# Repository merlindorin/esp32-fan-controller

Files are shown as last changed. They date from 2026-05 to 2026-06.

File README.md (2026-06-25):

<div align="center">

# ESP32 Fan Controller

**A small KiCad board to keep my home server cabinet cool. 4 PWM fans, 4 temperature probes, one ESP32.**








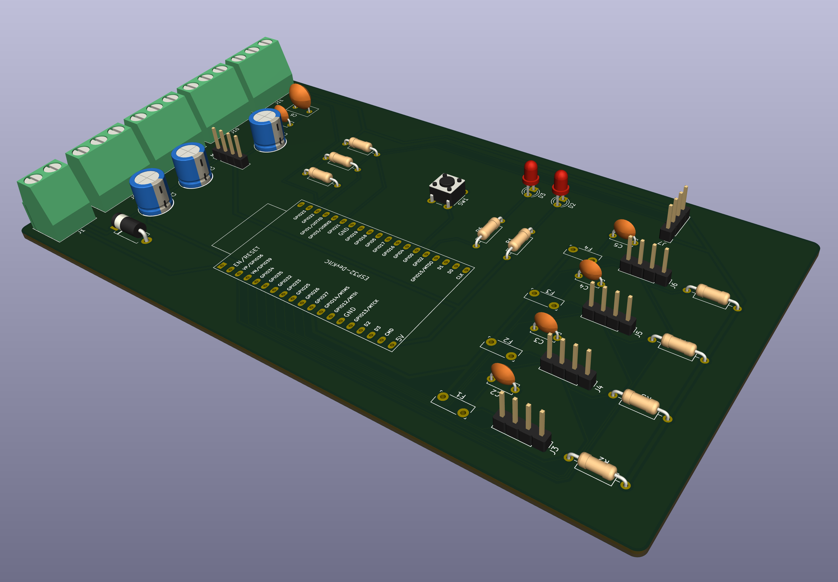
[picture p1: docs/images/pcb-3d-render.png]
ESP32 Fan Controller, KiCad 3D render


</div>

## Why this exists

My home servers live in a small cabinet, hidden inside a piece of furniture I built around them. It is a credenza with a stone top, a perforated metal grille set into that top so the warm air can escape upward, and cane mesh side panels so fresh air can come in from below.

The room itself has air conditioning, but the cabinet does not. Without something actively pushing the warm air out, it just stacks up under the stone. So I needed a way to manage the airflow.

<table align="center">
  <tr>
    <td align="center">
      <a href="docs/images/server-cabinet.jpg">The server cabinet, with the perforated stone-top grille and cane-mesh panels, click for full size</a>
    </td>
  </tr>
  <tr>
    <td align="center"><sub>The cabinet. Stone top with the perforated exhaust grille against the wall, servers behind the cane mesh panels.</sub></td>
  </tr>
</table>

I started with two breadboard prototypes (see [How I got here](#how-i-got-here)). The first one was just about understanding the temperatures: where to put the probes, where it actually gets hot. The second one was for the fans, to see how they really move the air through that perforated stone grille.

Once both questions were answered, I designed this PCB. It is a small two layer board, all through-hole so I can solder it by hand on a Sunday afternoon, around €14 in parts. It runs [ESPHome](https://esphome.io/), which means it shows up directly in Home Assistant without writing any firmware.

The board is now soldered, mounted at the back of the cabinet, and the firmware in [`firmware/fancontroller.yaml`](firmware/fancontroller.yaml) keeps the two pairs of fans (one per side of the cabinet) under thermostatic control. A short press on the on-board button toggles between auto and manual; the yellow LED reflects that state.

<table align="center">
  <tr>
    <td align="center" width="50%">
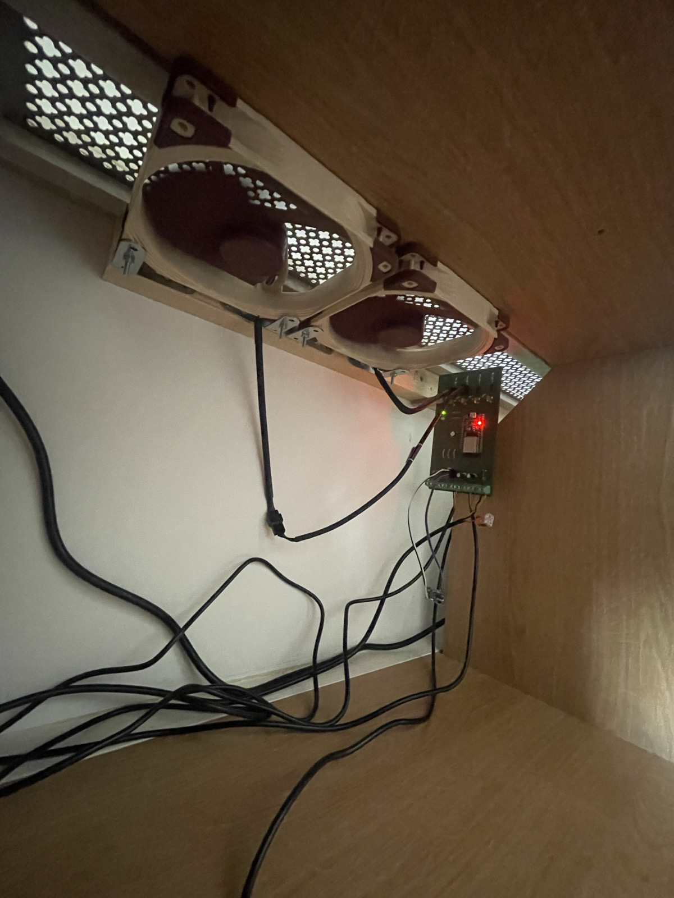
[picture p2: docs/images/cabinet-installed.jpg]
Two Noctua fans pulling air up through the perforated stone grille, controller mounted on the right wall of the cabinet, click for full size
      
    </td>
    <td align="center" width="50%">
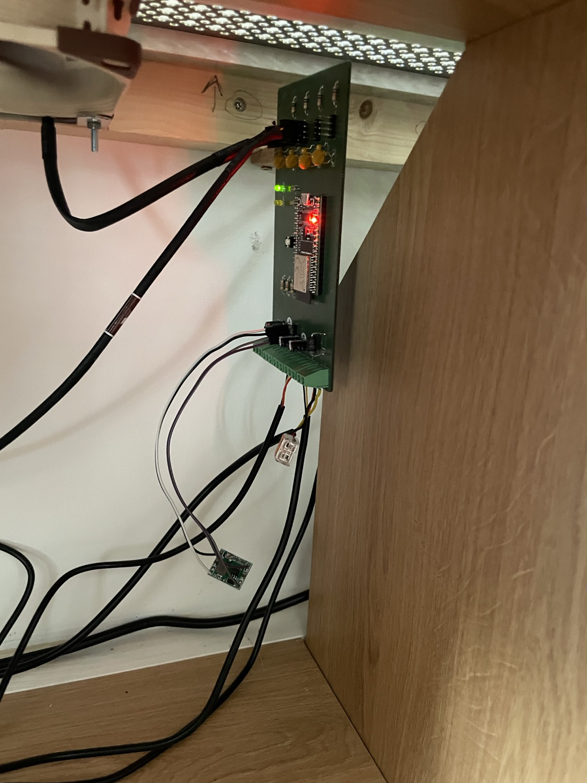
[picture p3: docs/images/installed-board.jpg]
The assembled controller mounted vertically inside the cabinet, with the DS18B20 probe and a fan cable plugged in, click for full size
      
    </td>
  </tr>
  <tr>
    <td align="center"><sub>Fans pulling air up through the perforated stone grille, controller mounted on the right wall.</sub></td>
    <td align="center"><sub>Board mounted vertically inside the cabinet, screw terminals on top, ESP32 power LED on.</sub></td>
  </tr>
</table>

## Contents

- [Features](#features)
- [Hardware overview](#hardware-overview)
  - [ESP32 GPIO map](#esp32-gpio-map)
- [Firmware (ESPHome)](#firmware-esphome)
- [How I got here](#how-i-got-here)
- [Build one yourself](#build-one-yourself)
- [Repository layout](#repository-layout)
- [Roadmap](#roadmap)
- [Discussion](#discussion)
- [License](#license)
- [Thanks](#thanks)

## Features

- 4 independent PWM fan channels (designed around Noctua NF-A14 PWM, but any standard 4-pin PC fan works)
- 4 tachometer (RPM) inputs, open-collector, with on-board pull-ups to 3.3 V
- 4 DS18B20 1-Wire temperature probes on a shared bus (single 4.7 kΩ pull-up)
- Single 12 V external input. An on-board MP1584EN buck module generates the 5 V for the ESP32
- Per-fan PTC fuse and a TVS diode at the 12 V input, for protection
- I²C expansion header (3.3 V / GND / SDA / SCL)
- Two indicator LEDs: a green one for power (lit when the 5 V rail is up) and a yellow one for status (driven by GPIO 2)
- A small tactile button for boot / user input, shared with GPIO 0
- Everything through-hole, so it can be hand-soldered without a reflow oven
- Bare board, 155 × 85 mm, with M3 mounting holes

## Hardware overview

| Block | Component |
|---|---|
| MCU | ESP32 DevKitC V4 (AZDelivery, 100 % Espressif layout) |
| Power | External 12 V / 2 A PSU, then on-board MP1584EN buck to 5 V |
| Fans | 4 Noctua NF-A14 PWM, plugged into 4-pin headers |
| Sensors | 4 DS18B20 waterproof probes on screw terminals |
| Protection | 1.5KE15A TVS on the 12 V input, 4 MF-R050 PTC fuses on the fans |
| Enclosure  | No enclosure for v1, just M3 mounting holes on the bare board |

PCB is two-layer, 155 × 85 mm, 1.6 mm thick.

<table align="center">
  <tr>
    <td align="center" width="50%">
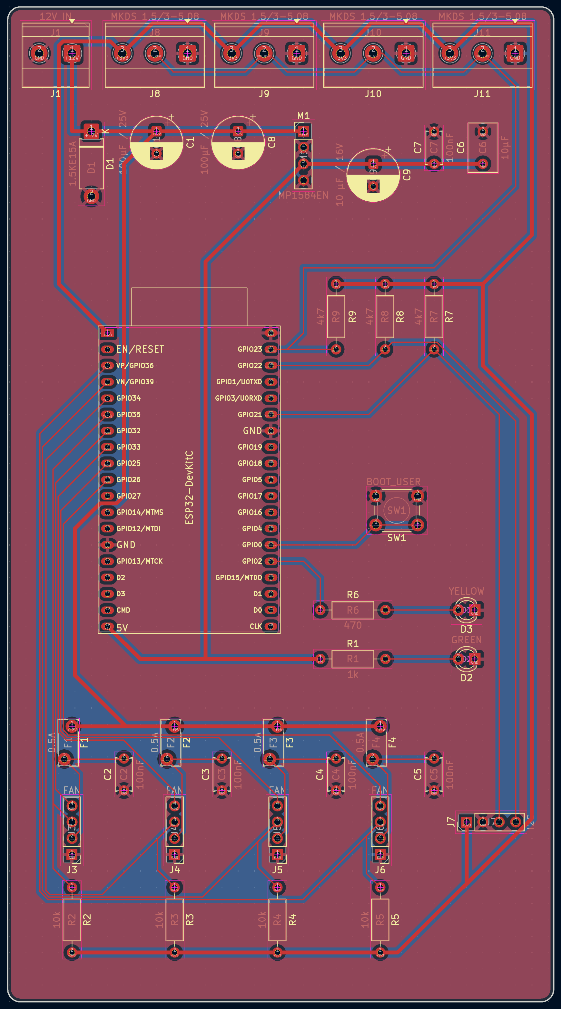
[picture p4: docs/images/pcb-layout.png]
PCB top-down layout, click for full size
      
    </td>
    <td align="center" width="50%">
      <a href="docs/images/pcb-3d-render.png">KiCad 3D render, click for full size</a>
    </td>
  </tr>
  <tr>
    <td align="center"><sub>2D layout. F.Cu in red, B.Cu in blue.</sub></td>
    <td align="center"><sub>KiCad 3D render of the assembled board.</sub></td>
  </tr>
</table>

### ESP32 GPIO map

| Connector | Side  | PWM (out) | Tach (in) |
|---|---|---|---|
| J3 | Right | GPIO 32 | GPIO 35 |
| J4 | Right | GPIO 33 | GPIO 34 |
| J5 | Left  | GPIO 25 | GPIO 39 |
| J6 | Left  | GPIO 26 | GPIO 36 |

| Pin | Use |
|---|---|
| 23 | 1-Wire bus (DS18B20 probes) |
| 21 / 22 | I²C SDA / SCL |
| 2 | Status LED (D3 yellow, R6 470 Ω) |
| 0 | Boot / user button (SW1) |

The probe on J8 covers the left fans (J5 + J6), the probe on J9 covers the right ones (J3 + J4). All four DS18B20 sockets (J8–J11) sit on the same 1-Wire bus, so the assignment is by ROM address in the YAML.

## Firmware (ESPHome)

The shipped firmware is [`firmware/fancontroller.yaml`](firmware/fancontroller.yaml). It exposes, in Home Assistant:

- Two fan controls (`Left Fans`, `Right Fans`), each driving that side's two fans in lockstep, plus an individual RPM sensor per physical fan (four in total, so a single seized fan is still visible)
- Two temperature probes (`Left Temp`, `Right Temp`) with their DS18B20 ROM addresses pinned
- A single `Auto Cooling` switch and three `Number` entities (`Cooling Setpoint`, `Fans Off Below`, `Fans Full Above`)
- A `Restart` button and a `User Button` binary sensor for the on-board SW1

When `Auto Cooling` is on, each side runs the same linear ramp on its own probe:

```
T ≤ Off Below            →   0 %     (silent)
Off Below < T < Setpoint →   0 → 60 % (gentle correction)
Setpoint ≤ T < Full Above → 60 → 100 % (aggressive)
T ≥ Full Above           → 100 %     (max effort)
```

The setpoint sits inside the band on purpose, so a stable cabinet parks the fans at around 60 % instead of oscillating between full speed and off. All three thresholds are editable live from HA; defaults are 24 / 27 / 30 °C.

The on-board button toggles `Auto Cooling` on a short press, and reboots the ESP32 on a 3 s+ hold. The yellow LED follows `Auto Cooling`: on in auto, off in manual.

### Autonomous by design

The control loop runs entirely on the board, not in Home Assistant. That is deliberate. Each server already manages its own temperature through its own fans; this controller's job is to keep the enclosure itself in range, and it has to keep doing that even when nothing is around to tell it to.

Home Assistant here runs on one of my Kubernetes nodes, which lives in the very rack this board is cooling. Relying on it to cool the rack it runs in is a chicken-and-egg problem: if that node is the one overheating, HA could be the first thing to go down. So the thermostatic logic lives on the ESP32 itself. If HA is unreachable, the board keeps reading its probes and driving the fans on its own, the servers keep handling their own thermal management, and everything stays under control independently.

The result is layered, autonomous cooling instead of a central brain that could take itself down and put the other nodes at thermal risk. Home Assistant is for visibility and live tuning, not a dependency for the rack to stay cool.

<table align="center">
  <tr>
    <td align="center" width="50%">
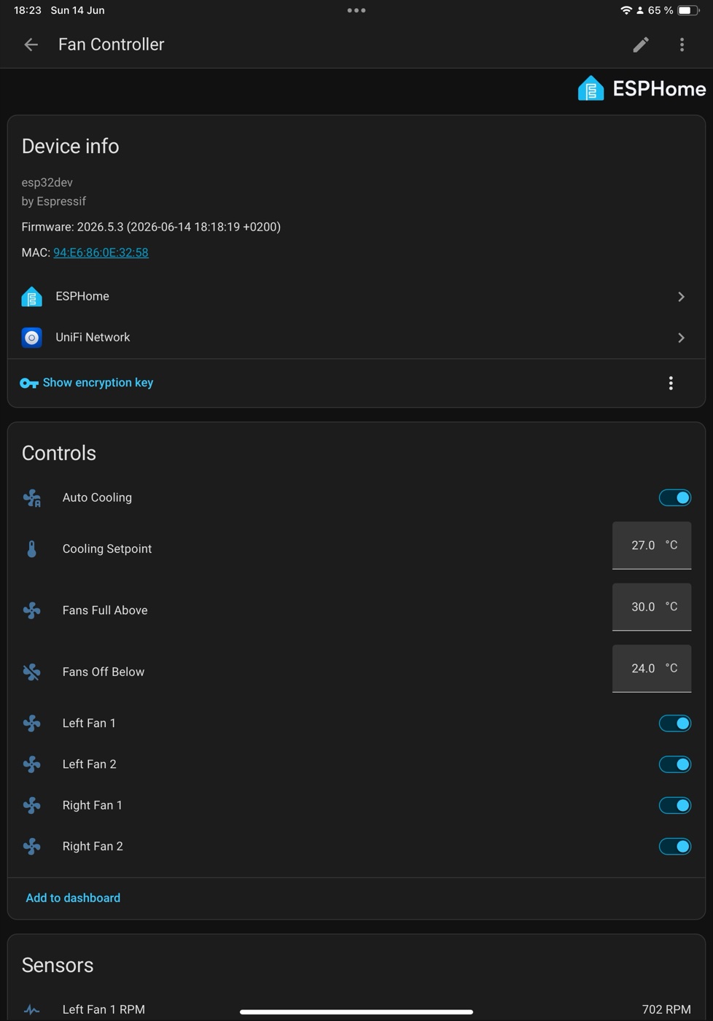
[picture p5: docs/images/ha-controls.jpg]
Home Assistant device controls: Auto Cooling switch, three setpoint numbers, two fan toggles, click for full size
      
    </td>
    <td align="center" width="50%">
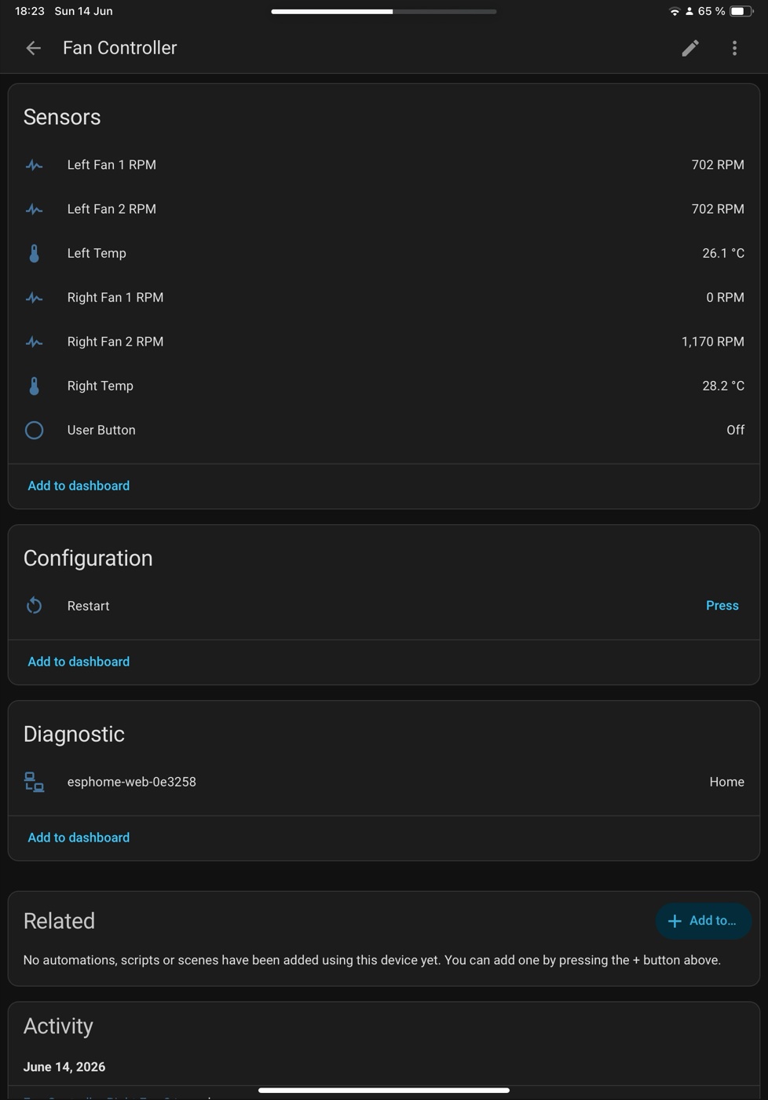
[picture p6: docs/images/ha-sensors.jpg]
Home Assistant sensors page: left and right RPM and temperatures, click for full size
      
    </td>
  </tr>
  <tr>
    <td align="center"><sub>Device controls: auto cooling, thresholds, per-side fan toggles.</sub></td>
    <td align="center"><sub>Sensors: per-side RPM and temperature.</sub></td>
  </tr>
</table>

The build / flash / dashboard commands are wrapped in a [`Taskfile.yml`](Taskfile.yml). With [Task](https://taskfile.dev/) installed (`brew install go-task`):

```
task               # list available tasks
task config        # validate the YAML
task upload        # compile and OTA-flash fancontroller.local
task flash-usb PORT=/dev/cu.wchusbserial8330   # first-time USB flash
task logs          # stream logs over the network
task dashboard     # local ESPHome dashboard on :6052
```

Before the first flash, copy `firmware/secrets.example.yaml` to `firmware/secrets.yaml` and fill it in (Wi-Fi, API key, OTA password). `secrets.yaml` is git-ignored.

## How I got here

Before committing to a PCB, I validated the design with two breadboard stages.

### Stage 1, temperature monitoring with Home Assistant

I started with an ESP32 **LoLin** board and **two DS18B20 probes**, flashed with [ESPHome](https://esphome.io/) and added to Home Assistant. The question for this stage was simple: what does the temperature actually do in the server cabinet? It gave me the baseline graphs that justified active cooling, and it told me where the probes should sit (intake, exhaust, ambient).

The ESPHome YAML I used is kept here for reference: [`docs/stage1-lolin32-esphome.yaml`](docs/stage1-lolin32-esphome.yaml). Shared 1-Wire bus on GPIO 4, two `dallas_temp` entries by 64-bit address.

<table align="center">
  <tr>
    <td align="center" width="50%">
      <a href="docs/images/proto-lolint-esp.jpg">ESP32 LoLin with 2 DS18B20 probes on a protoboard, click for full size</a>
    </td>
    <td align="center" width="50%">
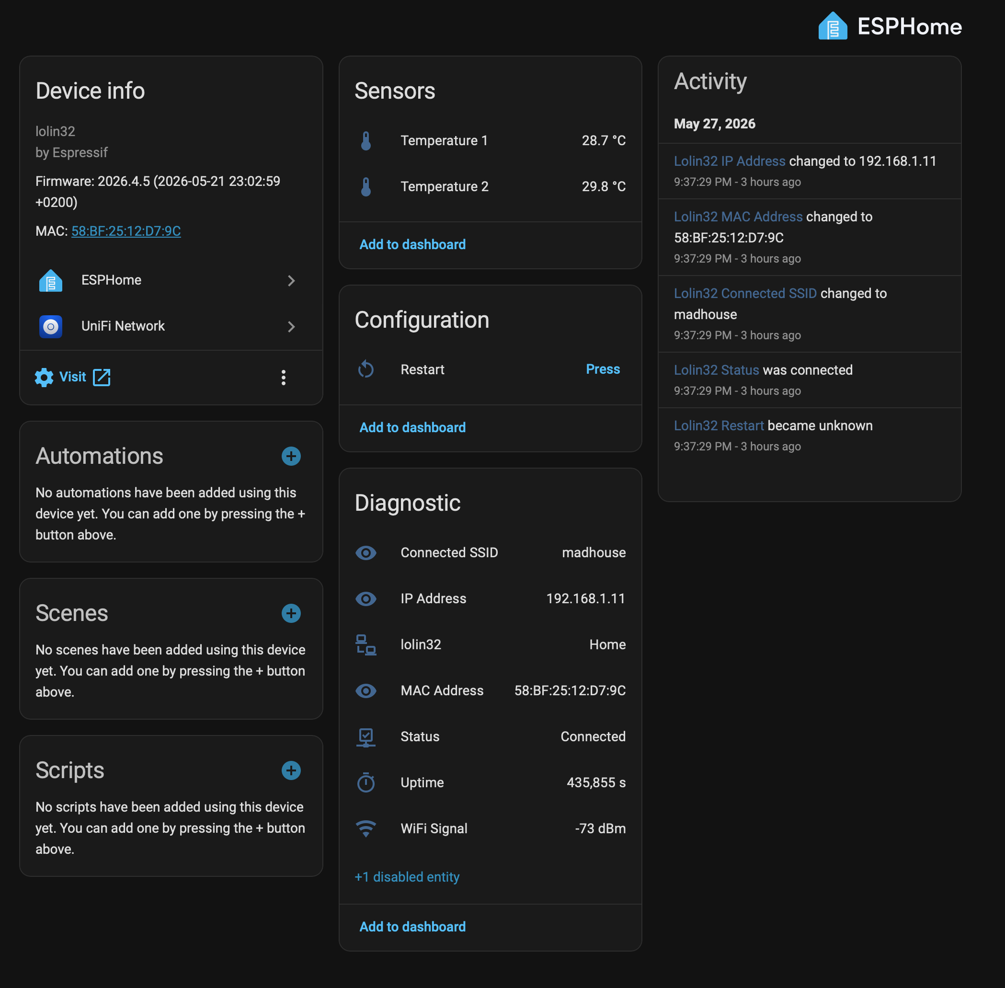
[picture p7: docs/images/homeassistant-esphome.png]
Home Assistant device page for the LoLin32, click for full size
      
    </td>
  </tr>
  <tr>
    <td align="center"><sub>ESP32 LoLin with two DS18B20 probes.</sub></td>
    <td align="center"><sub>Home Assistant device page, both probes live (28.7 °C and 29.8 °C).</sub></td>
  </tr>
</table>

### Stage 2, the fan bench

For the second stage, I drove a fan directly from a separate breadboard, to actually measure how the airflow influences the temperature. Fan position, speed versus Δtemperature, how fast the cabinet responds. This is where I confirmed that the Noctua NF-A14 was the right fan, validated the PWM strategy, and figured out the per-fan power budget.

<table align="center">
  <tr>
    <td align="center">
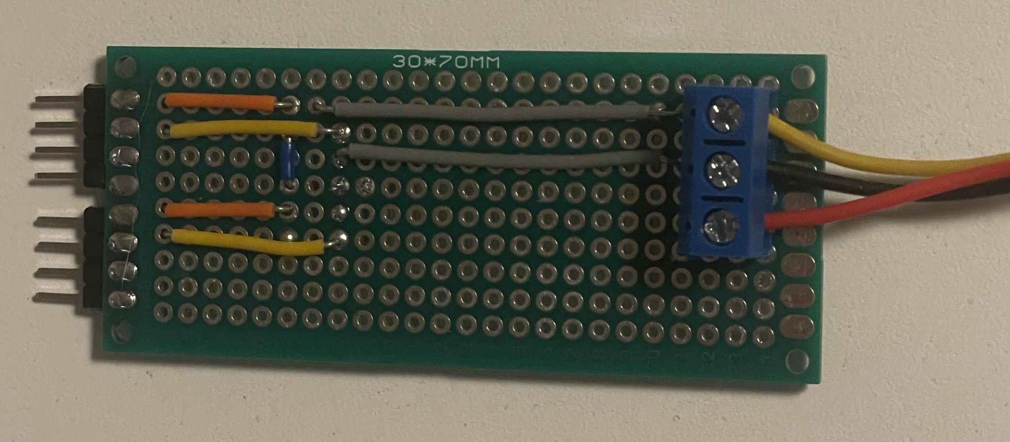
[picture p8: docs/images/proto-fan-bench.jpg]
Fan power and airflow test on a 30 by 70 mm protoboard, click for full size
      
    </td>
  </tr>
  <tr>
    <td align="center"><sub>Fan power and airflow test on a 30 × 70 mm protoboard.</sub></td>
  </tr>
</table>

The PCB in this repository is the consolidation of both stages: 4 probes (intake, exhaust, two ambient) and 4 PWM-controlled fans on a single board instead of breadboards.

## Build one yourself

1. **Order the bare PCB.** Any fab works, I used [Aisler](https://aisler.net/). You can upload `kicad/esp32-fan-controller.kicad_pro` directly, or export gerbers first if your fab needs them.
2. **Order the parts**, around €14 excluding VAT and shipping. The quick-paste block in [`bom/ORDER.md`](bom/ORDER.md) is verified against live Farnell France stock. Paste it into Farnell's Quick Paste / Multi-Add tool. The full BOM with notes is in [`BOM.md`](BOM.md).
3. **Pre-set the MP1584EN buck module to 5.00 V before soldering it in.** Apply 12 V on its input with a bench supply, and turn the trimpot until the output reads 5.00 V.
4. **Hand-solder.** All through-hole. The order I would suggest: passives, then diodes and LEDs, then sockets and headers, then screw terminals, and finally the ESP32 socket.
5. **Power-up check.** 12 V on J1, confirm 5 V at the M1 output pin, then plug in the ESP32. Watch the polarity at J1: D1 is a 1.5KE15A TVS, so a reversed wire short-circuits the input through the diode.

<table align="center">
  <tr>
    <td align="center">
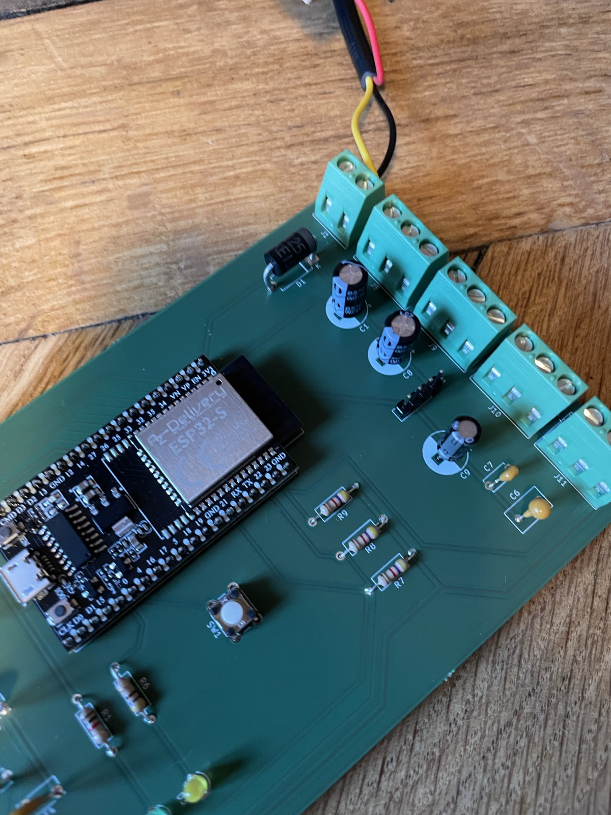
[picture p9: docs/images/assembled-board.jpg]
Assembled controller on a workbench, mid power-up check with two test leads on J1, click for full size
      
    </td>
  </tr>
  <tr>
    <td align="center"><sub>Mid power-up check: 12 V test leads on J1 before plugging in the ESP32.</sub></td>
  </tr>
</table>

6. **Flash [ESPHome](https://esphome.io/).** First time over USB, after that over the air:

   ```
   cp firmware/secrets.example.yaml firmware/secrets.yaml   # fill in Wi-Fi etc.
   task flash-usb PORT=/dev/cu.wchusbserial...              # initial flash
   task upload                                              # subsequent OTAs
   ```

   Details in [Firmware (ESPHome)](#firmware-esphome).

## Repository layout

```
.
├── kicad/                            # KiCad 10 project (schematic and PCB)
├── firmware/                         # ESPHome YAML for the v1 board
│   ├── fancontroller.yaml            # Shipped firmware
│   └── secrets.example.yaml          # Template for secrets.yaml (git-ignored)
├── bom/                              # BOM CSV and ordering sheets
│   └── orders/                       # Generated distributor cart CSVs
├── docs/
│   ├── images/                       # Photos, schematic renders, screenshots
│   └── stage1-lolin32-esphome.yaml   # ESPHome config used on the temperature prototype
├── BOM.md                            # Human-readable BOM with notes
├── Taskfile.yml                      # `task config / upload / logs / dashboard`
├── LICENSE                           # MIT
└── README.md
```

## Roadmap

**Next**

- [ ] Replace the missing right-side fan (J4) once the second NF-A14 arrives
- [ ] Long-term temperature graph in Grafana, to see how the auto-cooling curve actually plays out over a week

**Later**

- [ ] An actual enclosure for the PCB. The CamdenBoss CNMB/9 DIN-rail kit is a candidate, the board is already short-edge-connector friendly
- [ ] A v2 silkscreen polish, based on what I learned during assembly (polarity marks on J1, clearer pin-1 on the fan headers)

**Done**

- ✅ Schematic, ERC clean
- ✅ PCB layout, DRC clean, 0 violations, 0 unconnected
- ✅ Bare PCB ordered (Aisler)
- ✅ BOM verified against live Farnell stock
- ✅ Components ordered (Farnell)
- ✅ Board assembled and brought up on the bench
- ✅ Mounted in the cabinet, three fans and two DS18B20s live
- ✅ ESPHome config shipped: two per-side fan groups (4 PWM channels, 4 RPM sensors), 2 temp probes, thermostatic auto-cooling, button + LED status

## Discussion

Shared and discussed here:

- [r/esp32](https://www.reddit.com/r/esp32/comments/1ueic1q/esp32_fan_controller_for_my_home_server_cabinet/)
- [r/homeassistant](https://www.reddit.com/r/homeassistant/comments/1ueijpl/esphome_fan_controller_for_my_server_cabinet/)

## License

MIT, see [LICENSE](LICENSE). Hardware design files are released under the same terms, so feel free to fork, modify, fabricate and share.

## Thanks

- The KiCad team for the EDA suite
- Espressif for the ESP32 and the DevKitC reference design
- AZDelivery for an affordable ESP32 DevKitC V4 clone
- [ESPHome](https://esphome.io/), which turned the Stage 1 prototype into a one evening job
- [openotters](https://github.com/openotters/openotters), which I used as a template for this README

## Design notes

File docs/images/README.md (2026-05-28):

# Images

Drop project photos and screenshots here. Referenced from the top-level `README.md`.

Suggested filenames (match the references in the main README):

- `proto-lolint-esp.jpg` — Stage 1: ESP32 LoLin + 2× DS18B20 on a protoboard (present)
- `proto-fan-bench.jpg` — Stage 2: fan power / airflow test on a 30×70 mm protoboard (present)
- `proto-fan-bench.jpg` — second breadboard wired to drive fans and log temperature vs airflow
- `homeassistant-esphome.png` — Home Assistant device page for the LoLin32 (present)
- `server-cabinet.jpg` — the stone-topped server cabinet the airflow exists to manage (present)
- `kicad-schematic.png` — export of the final hierarchical schematic
- `pcb-layout.png` — KiCad PCB editor 2D top-down view (present)
- `pcb-3d-render.png` — KiCad 3D viewer render of the assembled board (present)
- `assembled-board.jpg` — final assembled board
- `enclosure-mounted.jpg` — board installed in the CamdenBoss CNMB/9 on DIN rail

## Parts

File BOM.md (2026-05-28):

# Bill of Materials — ESP32 Fan Controller

Server airflow controller: 4× PWM fans driven by ESP32, regulated from 4× DS18B20 temperature probes.

## Main components

| Qty | Part | Notes |
|----:|---|---|
| 1 | ESP32 DevKitC V4 | MCU board, mounted on PCB via female headers |
| 1 | 12V/2A PSU | External — DIN-rail (e.g. Mean Well HDR-30-12) or desktop brick |
| 1 | MP1584EN buck module (pre-built, adjustable) | 12V→5V step-down for ESP32. Pre-set trimpot to **5.00 V** before installing |
| 4 | Noctua NF-A14 PWM | 12V, 0.13A each (0.52A total on 12V rail) |
| 4 | DS18B20 waterproof probe | 1-Wire digital temp sensor, shared bus |
| 4 | Phoenix MKDS 1,5/3-5,08 (3-pin screw terminal block, 5.08 mm pitch) | For DS18B20 probes — wires enter through CNMB/9 perforated terminal guards. Pin 1=GND, Pin 2=DATA, Pin 3=+3V3. Same family as J1. |
| 4 | 4-pin PC fan header (2.54mm pitch) | **NOT** Molex KK 254 — keying differs, Noctua plugs won't mate |
| 1 | 2-pin terminal block (5.08mm pitch) | 12V input |
| 1 | 1×4 pin header, 2.54 mm pitch | Socket for MP1584EN module (M1) |
| 2 | Female header 1×19, 2.54mm pitch | ESP32 DevKitC V4 socket |

## Passives

| Qty | Part | Purpose |
|----:|---|---|
| 1 | 4.7 kΩ resistor (0603 or THT) | 1-Wire bus pull-up to 3.3V |
| 4 | 10 kΩ resistor (0603 or THT) | Tach signal pull-up to 3.3V |
| 1 | 100 µF electrolytic, 25V | 12V rail bulk decoupling (C1, near J2) |
| 1 | 100 µF electrolytic, 25V | Buck input bulk (C8, at M1 +12V pin) |
| 1 | 100 µF electrolytic, 25V | Buck output decoupling (C9, at M1 +5V pin) |
| 1 | 10 µF ceramic, 10V | 3.3V rail decoupling |
| 4 | 100 nF ceramic, 50V | Per-fan VCC decoupling |
| 1 | 10 µF ceramic, 16V | 5V rail decoupling near ESP32 socket (C6) |

## Protection & debug

| Qty | Part | Purpose |
|----:|---|---|
| 4 | PTC fuse, 0.5A hold / 1A trip (e.g. Bourns MF-R050) | Per-fan 12V protection |
| 1 | TVS diode, 1.5KE15A (axial DO-15 THT) | 12V input transient protection |
| 1 | LED (green, 3mm) + 1 kΩ resistor | Power indicator |
| 1 | LED (blue/yellow, 3mm) + 1 kΩ resistor | Status, driven by ESP32 GPIO |
| 1 | Tactile pushbutton | Optional reset/user input |
| 1 | Pin header 1×4, 2.54mm pitch | I²C expansion (3.3V / GND / SDA / SCL) |

## Mechanical

| Qty | Part | Notes |
|----:|---|---|
| 1 | PCB | ~155 × 85 mm, 1.6 mm thick. Slides into CNMB/9 side slots; 4× M3 mounting holes (H1–H4) also present for standalone use |
| 4 | M3 standoff + screws, optional | For standalone PCB testing/mounting outside CNMB/9 |
| 1 | CamdenBoss CNMB/9/KIT | DIN rail enclosure, 9M (159 × 90 × 58 mm). Farnell `3954255`. Includes body + grey cover + 6× perforated terminal guards |

## Power budget

| Rail | Source | Consumers | Total draw | Margin |
|---|---|---|---:|---:|
| 12V | External 12V/2A | 4× NF-A14 @ 0.13A + buck input (~0.3A) | ~0.85A | ~1.15A |
| 5V | MP1584EN buck (3A) | ESP32 DevKitC V4 (~0.5A peak with WiFi) | ~0.5A | ~2.5A |
| 3.3V | ESP32 onboard LDO | DS18B20 ×4, pull-ups, LED | ~0.05A | comfortable |

## Design decisions (locked)

- **DS18B20 power mode:** standard 3-wire (VCC + DATA + GND). Cleaner, less noise-sensitive.
- **Expansion:** 1× I²C header (3.3V / GND / SDA / SCL) on free GPIO. No UART header (USB serial covers it).
- **Enclosure:** CamdenBoss CNMB/9/KIT (9M DIN rail, 159 × 90 × 58 mm). PCB slides into bottom side slots (Position A), max **86.5 × 156 mm**. Target PCB **155 × 85 mm**. No mounting holes — side slots only. Connectors exit the **short edges** (85 mm sides), through end-face terminal guards.
- **Power architecture:** single external 12V/2A PSU feeds the board through one 12V terminal block. On-board MP1584EN buck module generates 5V for the ESP32. No mains on the board.

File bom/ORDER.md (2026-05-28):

# Order Sheet — ESP32 Fan Controller

## Farnell France (1 board, no spares)

Paste this into Farnell **Quick Paste / Multi-Add** tool on [fr.farnell.com](https://fr.farnell.com/):

```
2507750,5
2579016,1
9451188,2
1907193,1
2765092,1
1142509,1
1612439,1
9350420,4
3041529,1
2356155,6
3041530,4
2329626,1
2329609,4
2329680,1
2329685,3
176432,1
```

**Total: ~£11.65 (~€14 excl. VAT/shipping, ~€22 all-in)**

> **Verified 2026-05-27**: all SKUs above are STOCKED on Farnell UK with adequate inventory. Four parts were swapped from the initial pick — the originals were either NO_LONGER_STOCKED, out-of-stock, or DIRECT_SHIP (longer lead time).

### Detailed Farnell BOM

| Farnell SKU | Qty | MPN | Description | £/ea | £Total |
|---|----:|-----|---|-----:|---:|
| 2507750 | 5 | K104K15X7RF5UH5 | 100nF 50V X7R radial (C2-C5, C7) | 0.08 | 0.41 |
| 2579016 | 1 | TAP106K016SCS | 10µF 16V tantalum (C6) | 0.96 | 0.96 |
| 9451188 | 2 | MCGPR25V107M6.3X11 | 100µF 25V electrolytic (C1, C8) — Multicomp Pro | 0.15 | 0.30 |
| 1907193 | 1 | ECA1CHG100 | 10µF 16V electrolytic (C9) | 0.21 | 0.21 |
| 2765092 | 1 | 1.5KE15A | TVS diode DO-201 (D1) — Littelfuse | 0.30 | 0.30 |
| 1142509 | 1 | L-934LGD | 3mm green LED (D2) — Kingbright | 0.09 | 0.09 |
| 1612439 | 1 | TLLY4400 | 3mm yellow LED (D3) — Vishay | 0.31 | 0.31 |
| 9350420 | 4 | MF-R050 | PTC 0.5A radial (F1-F4) | 0.34 | 1.37 |
| 3041529 | 1 | 1715721 | Phoenix MKDS 2-pin (J1) | 1.20 | 1.20 |
| 2356155 | 6 | 61300411121 | Pin Header 1×4 2.54mm (J3-J7, M1) | 0.08 | 0.50 |
| 3041530 | 4 | 1715734 | Phoenix MKDS 3-pin (J8-J11) | 1.52 | 6.08 |
| 2329626 | 1 | CFR25J1K0 | 1kΩ axial 5% (R1) | 0.04 | 0.04 |
| 2329609 | 4 | CFR25J10K | 10kΩ axial 5% (R2-R5) | 0.03 | 0.11 |
| 2329680 | 1 | CFR25J470R | 470Ω axial 5% (R6) | 0.04 | 0.04 |
| 2329685 | 3 | CFR25J4K7 | 4.7kΩ axial 5% (R7-R9) | 0.04 | 0.11 |
| 176432  | 1 | B3F-1000 | Tactile 6mm THT (SW1) | 0.12 | 0.12 |

⚠️ **MOQ tip:** Some lines (R series, LEDs, B3F-1000) have MOQ of 10 — Farnell may auto-bump qty. Worth keeping spares anyway for hand-soldering.

## Other Sources

| Item | Qty | Status | Source / Price |
|---|----:|---|---|
| ESP32 DevKitC V4 (AZDelivery, 100% Espressif layout) | 1 | **to order** | [az-delivery.de](https://www.az-delivery.de/en/products/esp-32-dev-kit-c-v4) — €13.99 |
| 12V/2A PSU (to be chosen) | 1 | **to source** | Amazon FR brick, or Mean Well brick at Farnell separately |
| MP1584EN buck module | 1 | ✓ owned | — |
| Noctua NF-A14 PWM 120mm | 4 | ✓ owned | — |
| DS18B20 waterproof probe | 4 | ✓ owned | — |

**Estimated total (excl. owned items, excl. PCB, excl. enclosure, excl. PSU):** ~€30–40 (Farnell €15–20 + ESP32 €14 + shipping)

## Notes

- **Spares**: for hand-soldering, consider ordering +25% extra on small passives (LEDs, resistors). Farnell's MOQ of 10 on most items already gives you spares.
- **PCB**: ordered separately from Aisler (~€30 for 3 boards)
- **Hot glue**: for fan plug strain relief — buy locally
- **M3 screws + standoffs**: if using standalone (CNMB/9 uses side slots, no holes needed)

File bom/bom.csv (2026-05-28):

Reference | Qty | Value | Footprint | MPN | Manufacturer | element14 | E14_Stock | Chosen_Distributor | Datasheet | Validated | DNP | Notes
C2(x4),C7 | 5 | 100nF | Disc_D5.0mm_W2.5mm_P5.00mm | K104K15X7RF5UH5 | Vishay | 2507750 |  | element14 |  |  |  | 4x fan instances + 1 ESP32
C6 | 1 | 10µF | Disc_D7.5mm_W4.4mm_P5.00mm | TAP106K016SCS | Kyocera AVX | 2579016
C8,C1 | 2 | 100µF / 25V | CP_Radial_D8.0mm_P3.50mm | MCGPR25V107M6.3X11 | Multicomp Pro | 9451188 |  | element14
C9 | 1 | 10 µF / 16V | CP_Radial_D8.0mm_P3.50mm | ECA1CHG100 | Panasonic | 1907193
D1 | 1 | 1.5KE15A | DO-15_P10.16mm_Horizontal | 1.5KE15A | Littelfuse | 2765092 |  | element14
D2 | 1 | GREEN | LED_D3.0mm | L-934LGD | Kingbright | 1142509 |  | element14
D3 | 1 | YELLOW | LED_D3.0mm | TLLY4400 | Vishay | 1612439 |  | element14
F1-F4 | 4 | 0.5A | Fuse_Bourns_MF-RG300 | MF-R050 | Bourns | 9350420 |  | element14 |  |  |  | 4x fan instances
J1 | 1 | 12V_IN | TerminalBlock_Phoenix_MKDS-1,5-2-5.08_1x02_P5.08mm_Horizontal | 1715721 | Phoenix Contact | 3041529
J3-J6 | 4 | FAN | PinHeader_1x04_P2.54mm_Vertical | 61300411121 | Wurth Elektronik | 2356155 |  | element14 |  |  |  | 4x fan headers
J7 | 1 | I2C | PinHeader_1x04_P2.54mm_Vertical | 61300411121 | Wurth Elektronik | 2356155
J10,J9,J8,J11 | 4 | MKDS 1,5/3-5,08 | TerminalBlock_Phoenix_MKDS-1,5-3-5.08_1x03_P5.08mm_Horizontal | 1715734 | Phoenix Contact | 3041530
M1 | 1 | MP1584EN | PinHeader_1x04_P2.54mm_Vertical | 61300411121 | Wurth Elektronik | 2356155
R1 | 1 | 1k | Axial_DIN0207_L6.3mm_D2.5mm_P10.16mm_Horizontal | CFR25J1K0 | TE Connectivity | 2329626
R2-R5 | 4 | 10k | Axial_DIN0207_L6.3mm_D2.5mm_P10.16mm_Horizontal | CFR25J10K | TE Connectivity | 2329609 |  | element14 |  |  |  | 4x tach pull-ups
R6 | 1 | 470 | Axial_DIN0207_L6.3mm_D2.5mm_P10.16mm_Horizontal | CFR25J470R | TE Connectivity | 2329680
R7,R8,R9 | 3 | 4k7 | Axial_DIN0207_L6.3mm_D2.5mm_P10.16mm_Horizontal | CFR25J4K7 | TE Connectivity | 2329685
SW1 | 1 | BOOT_USER | SW_PUSH_6mm | B3F-1000 | Omron | 176432
U1 | 1 | ESP32-DevKitC | ESP32-DevKitC |  |  |  |  |  | https://docs.espressif.com/projects/esp-idf/zh_CN/latest/esp32/hw-reference/esp32/get-started-devkitc.html

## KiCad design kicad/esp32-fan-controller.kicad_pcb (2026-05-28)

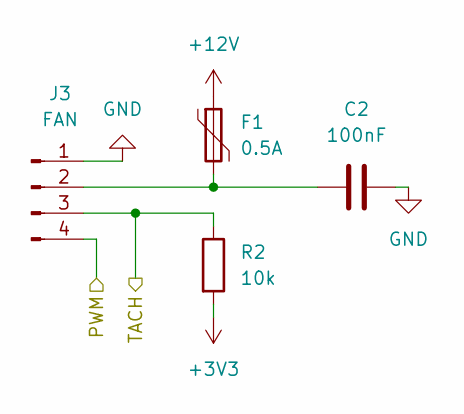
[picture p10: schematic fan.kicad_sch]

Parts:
C2: 100nF; C_Disc_D5.0mm_W2.5mm_P5.00mm; MPN K104K15X7RF5UH5; Farnell 2507750
F1: 0.5A; Fuse_Bourns_MF-RG300; MPN MF-R050; Farnell 9350420
J3: FAN; PinHeader_1x04_P2.54mm_Vertical; MPN 61300411121; Farnell 2356155
R2: 10k; R_Axial_DIN0207_L6.3mm_D2.5mm_P10.16mm_Horizontal; MPN CFR25J10K; Farnell 2329609

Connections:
+3V3: R2.2; also elsewhere on the board
+12V: F1.1; also elsewhere on the board
/PWM1: J3.4; also elsewhere on the board
/TACH1: J3.3, R2.1; also elsewhere on the board
GND: C2.1, J3.1; also elsewhere on the board
unnamed: C2.2, F1.2, J3.2

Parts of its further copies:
C3, C4, C5: 100nF; C_Disc_D5.0mm_W2.5mm_P5.00mm; MPN K104K15X7RF5UH5; Farnell 2507750
F2, F3, F4: 0.5A; Fuse_Bourns_MF-RG300; MPN MF-R050; Farnell 9350420
J4, J5, J6: FAN; PinHeader_1x04_P2.54mm_Vertical; MPN 61300411121; Farnell 2356155
R3, R4, R5: 10k; R_Axial_DIN0207_L6.3mm_D2.5mm_P10.16mm_Horizontal; MPN CFR25J10K; Farnell 2329609

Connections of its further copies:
+3V3: R3.2, R4.2, R5.2; also elsewhere on the board
+12V: F2.1, F3.1, F4.1; also elsewhere on the board
/PWM2: J4.4; also elsewhere on the board
/PWM3: J5.4; also elsewhere on the board
/PWM4: J6.4; also elsewhere on the board
/TACH2: J4.3, R3.1; also elsewhere on the board
/TACH3: J5.3, R4.1; also elsewhere on the board
/TACH4: J6.3, R5.1; also elsewhere on the board
GND: C3.1, C4.1, C5.1, J4.1, J5.1, J6.1; also elsewhere on the board
unnamed: C3.2, F2.2, J4.2
unnamed: C4.2, F3.2, J5.2
unnamed: C5.2, F4.2, J6.2

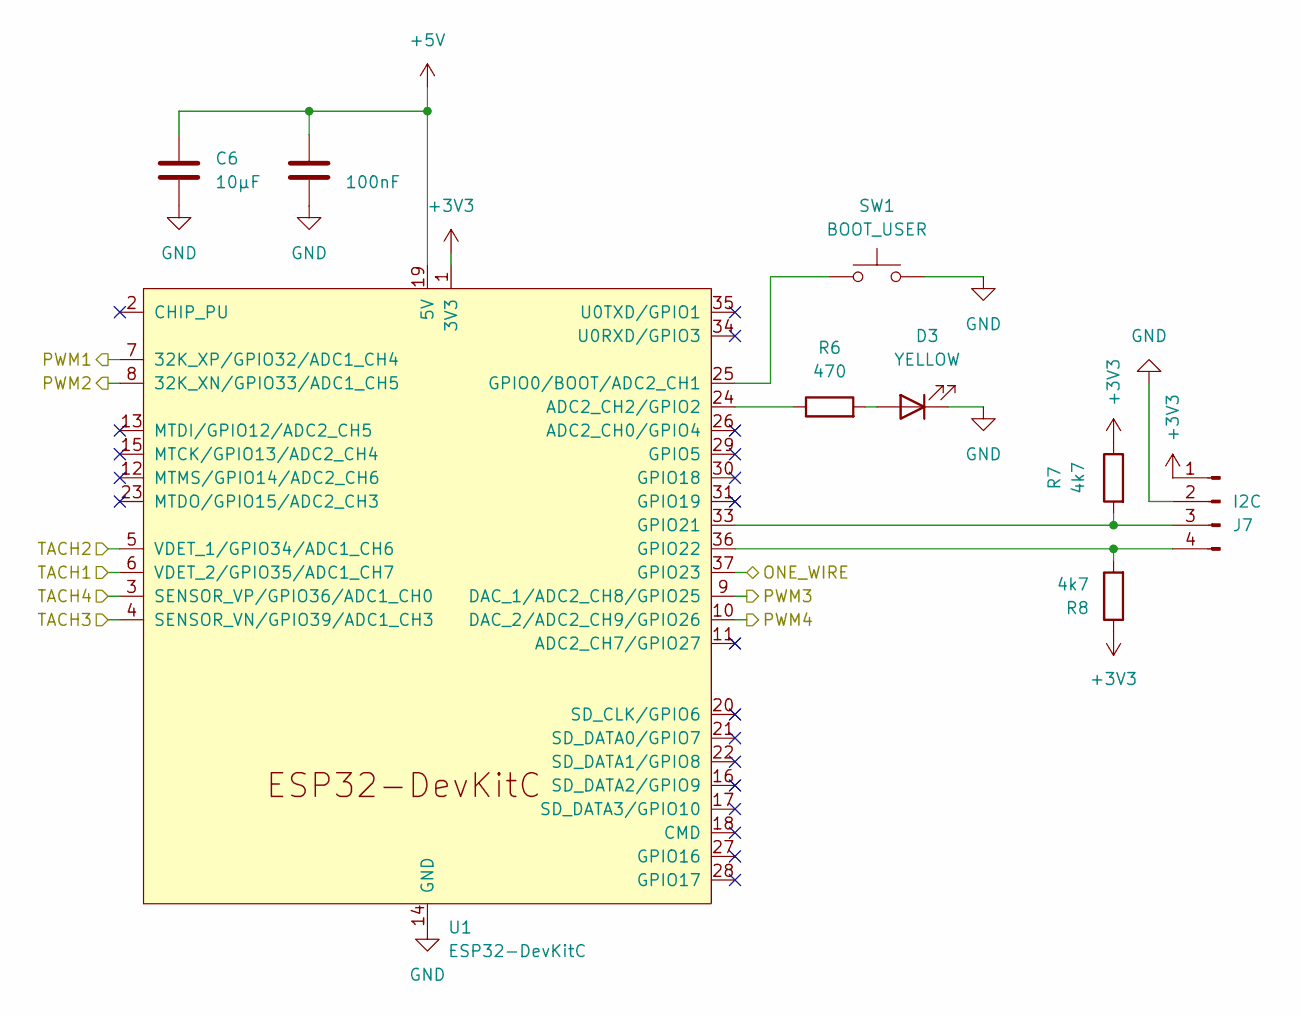
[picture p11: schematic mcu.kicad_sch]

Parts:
C6: 10µF; C_Disc_D7.5mm_W4.4mm_P5.00mm; MPN TAP106K016SCS; Farnell 2579016
C7: 100nF; C_Disc_D5.0mm_W2.5mm_P5.00mm; MPN K104K15X7RF5UH5; Farnell 2507750
D3: YELLOW; LED_D3.0mm; MPN TLLY4400; Farnell 1612439
J7: I2C; PinHeader_1x04_P2.54mm_Vertical; MPN 61300411121; Farnell 2356155
R6: 470; R_Axial_DIN0207_L6.3mm_D2.5mm_P10.16mm_Horizontal; MPN CFR25J470R; Farnell 2329680
R7, R8: 4k7; R_Axial_DIN0207_L6.3mm_D2.5mm_P10.16mm_Horizontal; MPN CFR25J4K7; Farnell 2329685
SW1: BOOT_USER; SW_PUSH_6mm; MPN B3F-1000; Farnell 176432
U1: ESP32-DevKitC

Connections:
+3V3: J7.1, R7.1, R8.1, U1.1 (3V3); also elsewhere on the board
+5V: C6.1, C7.1, U1.19 (5V); also elsewhere on the board
/ONE_WIRE: U1.37 (GPIO23); also elsewhere on the board
/PWM1: U1.7 (32K_XP/GPIO32/ADC1_CH4); also elsewhere on the board
/PWM2: U1.8 (32K_XN/GPIO33/ADC1_CH5); also elsewhere on the board
/PWM3: U1.9 (DAC_1/ADC2_CH8/GPIO25); also elsewhere on the board
/PWM4: U1.10 (DAC_2/ADC2_CH9/GPIO26); also elsewhere on the board
/TACH1: U1.6 (VDET_2/GPIO35/ADC1_CH7); also elsewhere on the board
/TACH2: U1.5 (VDET_1/GPIO34/ADC1_CH6); also elsewhere on the board
/TACH3: U1.4 (SENSOR_VN/GPIO39/ADC1_CH3); also elsewhere on the board
/TACH4: U1.3 (SENSOR_VP/GPIO36/ADC1_CH0); also elsewhere on the board
GND: C6.2, C7.2, D3.1 (K), J7.2, SW1.2, U1.14 (GND), U1.32 (GND), U1.38 (GND); also elsewhere on the board
unnamed: D3.2 (A), R6.2
unnamed: J7.3, R7.2, U1.33 (GPIO21)
unnamed: J7.4, R8.2, U1.36 (GPIO22)
unnamed: R6.1, U1.24 (ADC2_CH2/GPIO2)
unnamed: SW1.1, U1.25 (GPIO0/BOOT/ADC2_CH1)

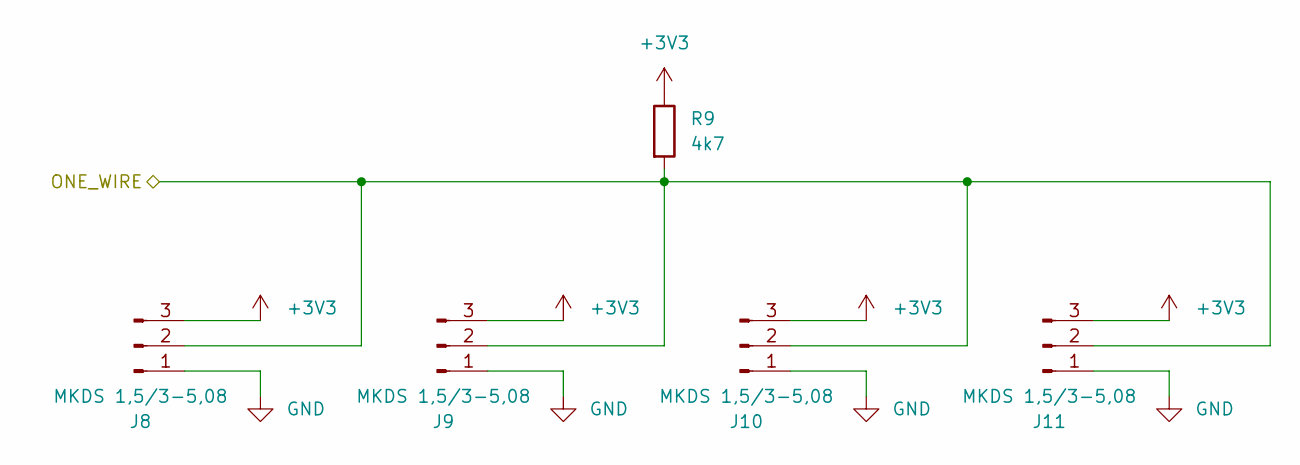
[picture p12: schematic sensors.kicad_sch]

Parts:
J8, J9, J10, J11: MKDS 1,5/3-5,08; TerminalBlock_Phoenix_MKDS-1,5-3-5.08_1x03_P5.08mm_Horizont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; MPN 1715734; Farnell 3041530
R9: 4k7; R_Axial_DIN0207_L6.3mm_D2.5mm_P10.16mm_Horizontal; MPN CFR25J4K7; Farnell 2329685

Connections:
+3V3: J8.3, J9.3, J10.3, J11.3, R9.1; also elsewhere on the board
/ONE_WIRE: J8.2, J9.2, J10.2, J11.2, R9.2; also elsewhere on the board
GND: J8.1, J9.1, J10.1, J11.1; also elsewhere on the board

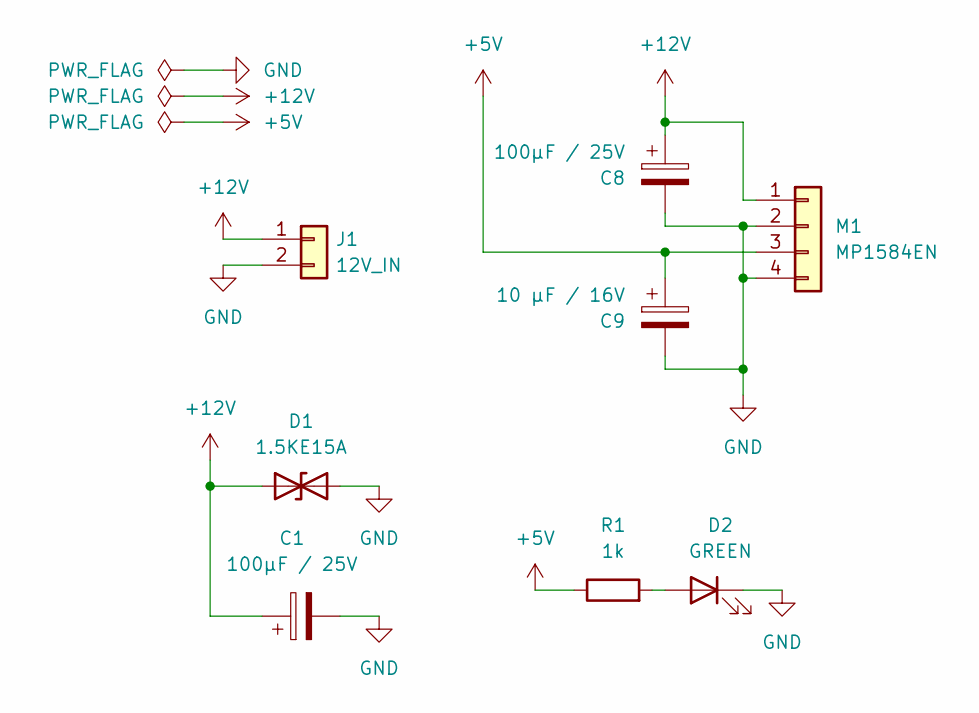
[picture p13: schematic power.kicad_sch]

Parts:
C1, C8: 100µF / 25V; CP_Radial_D8.0mm_P3.50mm; MPN MCGPR25V107M6.3X11; Farnell 9451188
C9: 10 µF / 16V; CP_Radial_D8.0mm_P3.50mm; MPN ECA1CHG100; Farnell 1907193
D1: 1.5KE15A; D_DO-15_P10.16mm_Horizontal; MPN 1.5KE15A; Farnell 2765092
D2: GREEN; LED_D3.0mm; MPN L-934LGD; Farnell 1142509
J1: 12V_IN; TerminalBlock_Phoenix_MKDS-1,5-2-5.08_1x02_P5.08mm_Horizont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; MPN 1715721; Farnell 3041529
M1: MP1584EN; PinHeader_1x04_P2.54mm_Vertical; MPN 61300411121; Farnell 2356155
R1: 1k; R_Axial_DIN0207_L6.3mm_D2.5mm_P10.16mm_Horizontal; MPN CFR25J1K0; Farnell 2329626

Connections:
+5V: C9.1, M1.3, R1.1; also elsewhere on the board
+12V: C1.1, C8.1, D1.1 (A1), J1.1, M1.1; also elsewhere on the board
GND: C1.2, C8.2, C9.2, D1.2 (A2), D2.1 (K), J1.2, M1.2, M1.4; also elsewhere on the board
unnamed: D2.2 (A), R1.2

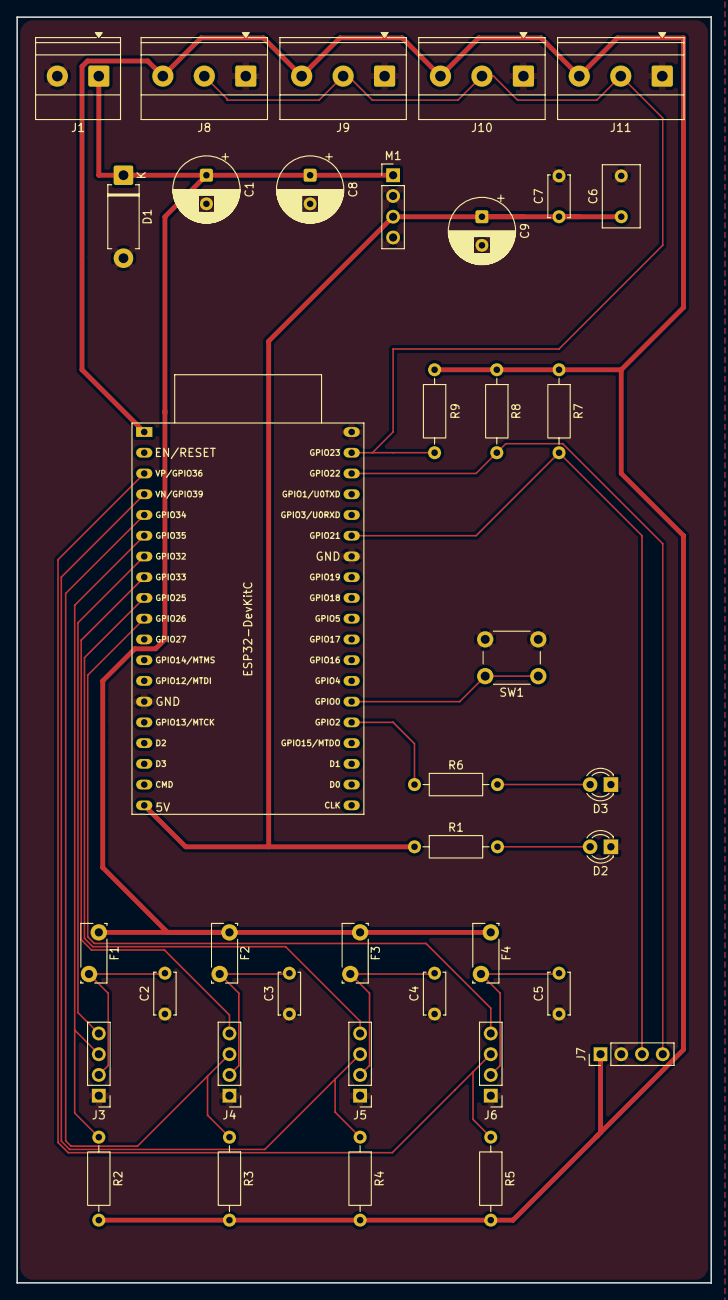
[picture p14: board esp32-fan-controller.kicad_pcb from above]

Board: 2 copper layers, 85.0 x 155.0 mm, 38 parts (0 on the bottom side), 23 nets.

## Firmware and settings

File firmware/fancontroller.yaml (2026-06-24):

esphome:
  name: fancontroller
  friendly_name: Fan Controller
  on_boot:
    priority: -100
    then:
      - script.execute: sync_status

esp32:
  board: esp32dev
  framework:
    type: arduino

logger:

api:
  encryption:
    key: !secret api_encryption_key

ota:
  - platform: esphome
    password: !secret ota_password

wifi:
  ssid: !secret wifi_ssid
  password: !secret wifi_password
  ap:
    ssid: "Fan Controller Fallback"
    password: !secret fallback_password

captive_portal:

# All DS18B20 probes share GPIO23 (J8..J11 wired to the same 1-Wire bus).
one_wire:
  - platform: gpio
    pin: GPIO23

# ===== Outputs =====
output:
  # Yellow LED D3 on GPIO2 — purely an auto/manual status indicator now.
  - platform: gpio
    id: status_led_out
    pin: GPIO2
  # PWM outputs (25 kHz, Noctua spec). Each cabinet's two fans share one logical
  # channel: a template output fans the level out to both LEDC pins in lockstep.
  - platform: ledc
    id: fan_right_1_pwm
    pin: GPIO32
    frequency: 25000Hz
  - platform: ledc
    id: fan_right_2_pwm
    pin: GPIO33
    frequency: 25000Hz
  - platform: ledc
    id: fan_left_1_pwm
    pin: GPIO25
    frequency: 25000Hz
  - platform: ledc
    id: fan_left_2_pwm
    pin: GPIO26
    frequency: 25000Hz
  - platform: template
    type: float
    id: fan_right_pwm
    write_action:
      - output.set_level: { id: fan_right_1_pwm, level: !lambda return state; }
      - output.set_level: { id: fan_right_2_pwm, level: !lambda return state; }
  - platform: template
    type: float
    id: fan_left_pwm
    write_action:
      - output.set_level: { id: fan_left_1_pwm, level: !lambda return state; }
      - output.set_level: { id: fan_left_2_pwm, level: !lambda return state; }

# SW1 (BOOT_USER) on GPIO0, press-to-ground momentary.
# WARNING: GPIO0 is a strapping pin. Don't hold it at boot/reset (forces download mode).
binary_sensor:
  - platform: gpio
    name: "User Button"
    id: user_button
    pin:
      number: GPIO0
      mode:
        input: true
        pullup: true
      inverted: true
    on_click:
      # Short press: toggle Auto/Manual
      - min_length: 50ms
        max_length: 800ms
        then:
          - switch.toggle: cooling_auto
      # Long hold: reboot
      - min_length: 3s
        max_length: 10s
        then:
          - button.press: restart_button

button:
  - platform: restart
    name: "Restart"
    id: restart_button

# ===== Fans =====
# One entity per cabinet, each driving both physical fans in lockstep.
# RIGHT cabinet: J3 + J4.  LEFT cabinet: J5 + J6.
fan:
  - platform: speed
    output: fan_right_pwm
    name: "Right Fans"
    id: fan_right
  - platform: speed
    output: fan_left_pwm
    name: "Left Fans"
    id: fan_left

sensor:
  # ===== Tachometers (Noctua = 2 pulses/rev → multiply 0.5) =====
  - platform: pulse_counter
    pin: { number: GPIO35, mode: { input: true } }
    name: "Right Fan 1 RPM"
    unit_of_measurement: "RPM"
    accuracy_decimals: 0
    update_interval: 5s
    filters: [multiply: 0.5]
  - platform: pulse_counter
    pin: { number: GPIO34, mode: { input: true } }
    name: "Right Fan 2 RPM"
    unit_of_measurement: "RPM"
    accuracy_decimals: 0
    update_interval: 5s
    filters: [multiply: 0.5]
  - platform: pulse_counter
    pin: { number: GPIO39, mode: { input: true } }
    name: "Left Fan 1 RPM"
    unit_of_measurement: "RPM"
    accuracy_decimals: 0
    update_interval: 5s
    filters: [multiply: 0.5]
  - platform: pulse_counter
    pin: { number: GPIO36, mode: { input: true } }
    name: "Left Fan 2 RPM"
    unit_of_measurement: "RPM"
    accuracy_decimals: 0
    update_interval: 5s
    filters: [multiply: 0.5]

  # ===== Temperature probes =====
  - platform: dallas_temp
    name: "Left Temp"
    id: temp_left
    address: 0x72000000be310828
    update_interval: 10s
    on_value:
      then:
        - script.execute: update_left_cooling
  - platform: dallas_temp
    name: "Right Temp"
    id: temp_right
    address: 0x27000000bf5ac728
    update_interval: 10s
    on_value:
      then:
        - script.execute: update_right_cooling
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

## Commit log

2026-05-28 feat: initial release of ESP32 Fan Controller v1
    KiCad 10 design of a standalone board that controls 4 PWM fans from 4
    DS18B20 temperature probes, driven by an ESP32 DevKitC V4. Built to
    manage the airflow of a home server cabinet hidden inside a piece of
    custom furniture.
    Hardware
    - 4 PWM fan channels with tachometer feedback (Noctua NF-A14 friendly)
    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
    [bom.csv, esp32-fan-controller.kicad_pcb, esp32-fan-controller.kicad_sch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]
2026-06-14 feat(firmware): ship ESPHome config with thermostatic auto-cooling
    Adds the firmware that actually runs on the assembled board, plus the
    glue around it:
    - firmware/fancontroller.yaml: 4 fans + 2 DS18B20 probes wired by ROM,
    per-side thermostatic linear ramp driven by Left Temp / Right Temp,
    Auto Cooling switch + 3 configurable thresholds, on-board button
    toggles auto/manual on short press and reboots on 3 s hold, yellow
    LED mirrors the auto state
    - firmware/secrets.example.yaml: template for the git-ignored secrets
    - Taskfile.yml: thin wrapper over the ESPHome CLI (config, compile,
    upload over IP, USB flash, logs, dashboard, clean)
    - README: refreshed status badges, new Firmware s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
    [fancontroller.yaml]
2026-06-24 feat(firmware): regroup fans into per-side Left/Right controls
    Collapse the four Home Assistant fan entities into two — `Left Fans`
    and `Right Fans` — each driving its side's two PWM channels in lockstep
    through a template output. The cooling scripts already ramped each side
    together, so this only changes the HA-facing entities, not the control
    behaviour.
    Per-fan tachometers are kept (four RPM sensors) so a single seized fan
    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
    [fancontroller.yaml]
